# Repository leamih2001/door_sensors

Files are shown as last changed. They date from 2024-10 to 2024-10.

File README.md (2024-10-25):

# door_sensors (Documentation for Access Control System)

1. Introduction
   The aim of the implemented system is to monitor entry and exit into a room, in this case the laboratory, using infrared
   light barriers, whereby photos are taken and facial recognition is then carried out. In this case, there are three main
   services that are orchestrated by the process engine. Communication between the services does not take place directly,
   but is coordinated by the CPEE, whereby the CPEE server calls scripts on the PC via http(s), which ensures, among other
   things, loose coupling and reusability.

2. Overview components
   The hardware components are as follows:
   - Infrared light barriers (LEFRIKO E18-D80NK)
   - Development board (ESP32-WROOM-32E)
   - Webcam (Logitech Streamcam)
   The ESP32 monitors the infrared light barriers and sends events to a central WebSocket client. There are three Flask-based
   services, which are:
   - Sensor Data Retrieval
   - Image Capture
   - Face Recognition

3. Hardware setup: Infrared light barrier and ESP32
   The ESP32 monitors four infrared light barriers, each of which detects people entering or leaving the laboratory. Two are
   mounted further up and the other two further down on the door frame to counteract the physical restrictions. The two
   brackets in which the sensors are located were produced using 3D printing, whereby there is a small opening underneath
   next to the two holes for the light barriers in which the ESP can be attached. The Arduino code regulates the behavior of
   the sensors and a small time delay was implemented to avoid overdetection. As soon as a sensor is triggered by a person
   entering or leaving the room, this event is sent to a websocket client via a message (“ENTRY” or “EXIT”).

4. Software architecture
   The process engine generally queries the sensor data service to determine whether an entry or exit has been detected.
   Based on this information, it triggers the services to perform the corresponding actions.
   
   4.1. Sensor data service
        This receives the events from the ESP via a websocket client and provides a REST endpoint /checkSensor to query the
        current sensor data status.
   
   4.2. Image capture service
        Here, the image is captured with the webcam when an entry or exit is detected. In addition, OpenCV is used here to
        achieve better quality for the subsequent face detection. The images are saved in a local directory and the REST
        endpoint /capture is used to trigger the image capture. The camera buffer is also emptied so that images are not
        simply overwritten.
   
   4.3. Face detection service
        For this service, OpenCV and a pre-trained hair cascade model are used to recognize faces. The REST endpoint /face
        detection is used to transmit the image for recognition.

5. Process
   - Access detection: A person enters (or leaves) the laboratory and thus breaks through the light barrier
     -> This event is registered in the ESP32 and sent to the sensor data service via a WebSocket.
   - Image capture: If “ENTRY” or “EXIT” is detected, the image capture service is called to capture an image of the person.
   - Face recognition: The captured image is forwarded to the face recognition service, which checks whether there are faces
     and, if so, where and how many there are on the captured image.
   - Process Engine: Coordinates the interactions between the services by querying events and initiating the next steps
     based on them.

6. Implementation details
   
   6.1. Arduino (ESP32)
        A WLAN connection is established and a new websocket server is started. In addition, the states of the infrared
        light barriers are read out and their logic is implemented. Depending on which light barrier (outer or inner) is
        broken through first, an entry or exit can be distinguished. At the end, the detected events are sent to the web
        socket client.

   6.2. Pyhonservices
        - Sensor data service: Implements communication via websockets with the ESP32. The service contains a websocket
          client that connects to the websocket server on the ESP and is notified via this connection when a light barrier
          is triggered. Threading is also used to process multiple messages in real time and thus reliably update the sensor
          status.
        - Image acquisition service: Uses OpenCV to capture images and store them in the local file system. A few
          optimizations, such as rotation(s) and resolution settings, have been made to ensure clearer images for face
          recognition.
        - Face recognition service: Processes the captured images and performs face recognition. Here, the recognition
          parameters have also been optimized to achieve better accuracy and consistency of face recognition.

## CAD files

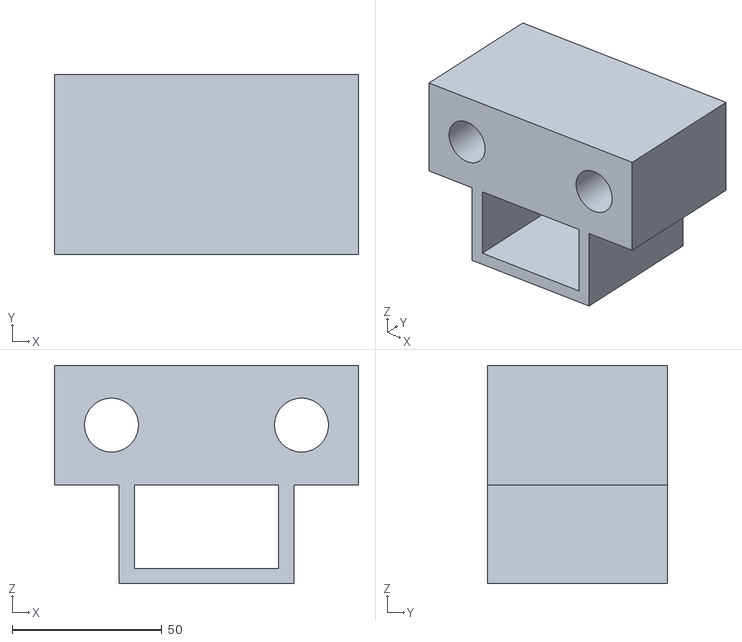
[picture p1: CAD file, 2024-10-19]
3DPrint.stl
101.6 x 60.0 x 73.0

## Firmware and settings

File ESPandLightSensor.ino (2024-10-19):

#include <ArduinoWebsockets.h>
#include <WiFi.h>

// Networkdata
const char* ssid = "Cocktail_Mixer";
const char* password = "process_hubby"; 

// Pins for the lightsensors
// Input for the first light barrier (ENTRY, bottom)
const int SENSOR_1_PIN = 16; 
// Input for the second light barrier (EXIT, bottom)
const int SENSOR_2_PIN = 17; 
// Input for the third light barrier (ENTRY, top)
const int SENSOR_3_PIN = 18; 
// Input for the forth light barrier (EXIT, top)
const int SENSOR_4_PIN = 19; 

// Status variables for the logic implementation of the infrared light barriers
bool entryDetectedBottom = false;
bool exitDetectedBottom = false;
bool entryDetectedTop = false;
bool exitDetectedTop = false;

// Time stamp for deactivation
// Variable for the lower sensors
unsigned long disableTimeBottom = 0;
// Variable for the upper sensors
unsigned long disableTimeTop = 0;  
// 2 second “pause” after breaking through the beam of a light barrier
const unsigned long disableDuration = 2000;

using namespace websockets;

WebsocketsServer server;
WebsocketsClient connectedClient; 

void setup() {
    Serial.begin(115200);
    Serial.println("Connect to WiFi...");

    // Connect to WiFi
    WiFi.begin(ssid, password);
    int retries = 0;
    while (WiFi.status() != WL_CONNECTED && retries < 15) {
        Serial.print(".");
        delay(1000);
        retries++;
    }

    if (WiFi.status() != WL_CONNECTED) {
        Serial.println("\nMistake: No WiFi connection");
        while (true) {
            // The system waits 5 seconds and then repeats the error message
            delay(5000);  
        }
    } else {
        Serial.println("\nWiFi connected");
        Serial.println("IP-Adress: ");
        Serial.println(WiFi.localIP());

        // Starting WebSocket-Server
        server.listen(80);

        // Defining the Pin-Modes
        pinMode(SENSOR_1_PIN, INPUT);
        pinMode(SENSOR_2_PIN, INPUT);
        pinMode(SENSOR_3_PIN, INPUT);
        pinMode(SENSOR_4_PIN, INPUT);
    }
}

void loop() {
    // Accepting the WebSocket connections
    while (!connectedClient.available()) {
        Serial.println("Waiting for Client connections");
        connectedClient = server.accept();

        if (connectedClient.available()) {
            Serial.println("Client connected");
        }
    }

    // Sensor logic only executed when the client is connected
    if (connectedClient.available()) {
        checkSensors();
    } else {
        Serial.println("No Client connected. Sensors deactivated.");
    }
}

void checkSensors() {
    unsigned long currentTime = millis();

    // Querying the individual statuses of the light barriers
    int Sensor1State = digitalRead(SENSOR_1_PIN);
    int Sensor2State = digitalRead(SENSOR_2_PIN);
    int Sensor3State = digitalRead(SENSOR_3_PIN);
    int Sensor4State = digitalRead(SENSOR_4_PIN);

    // Logic for lower sensors (only active if the upper sensors are not deactivated)
    if (currentTime - disableTimeBottom >= disableDuration) {
        if (Sensor1State == LOW && !entryDetectedBottom) { 
            entryDetectedBottom = true;
            Serial.println("Person enters the room (bottom).");
            logAccess("ENTRY (bottom)");
            sendMessageToClient("ENTRY");
            // Upper light barriers deactivated for 2 seconds
            disableTimeTop = currentTime;
            // Lower light barriers deactivated for 2 seconds
            disableTimeBottom = currentTime;
        } 
        else if (Sensor2State == LOW && !exitDetectedBottom) {
            exitDetectedBottom = true;
            Serial.println("Person leaves the room (bottom).");
            logAccess("EXIT (borrom)");
            sendMessageToClient("EXIT");
            // Upper light barriers deactivated for 2 seconds
            disableTimeTop = currentTime; 
            // Lower light barriers deactivated for 2 seconds
            disableTimeBottom = currentTime;
        }
    }

    // Logic for upper sensors (only active if the lower sensors are not deactivated)
    if (currentTime - disableTimeTop >= disableDuration) {
        if (Sensor3State == LOW && !entryDetectedTop) {
            entryDetectedTop = true;
            Serial.println("Person enters the room (top).");
            logAccess("ENTRY (top)");
            sendMessageToClient("ENTRY");
            // Lower light barriers deactivated for 2 seconds
            disableTimeBottom = currentTime; 
            // Upper light barriers deactivated for 2 seconds
            disableTimeTop = currentTime;  
        } 
        else if (Sensor4State == LOW && !exitDetectedTop) {
            exitDetectedTop = true;
            Serial.println("Person leaves the room (top).");
            logAccess("EXIT (top)");
            sendMessageToClient("EXIT");
            // Lower light barriers deactivated for 2 seconds
            disableTimeBottom = currentTime;
            // Upper light barriers deactivated for 2 seconds
            disableTimeTop = currentTime;
        }
    }

    // Reset the status variables when the light barriers are no longer blocked
    if (Sensor1State == HIGH) entryDetectedBottom = false;
    if (Sensor2State == HIGH) exitDetectedBottom = false;
    if (Sensor3State == HIGH) entryDetectedTop = false;
    if (Sensor4State == HIGH) exitDetectedTop = false;
}

// Sends message (if connection is established) to connected WebSocket client
void sendMessageToClient(String message) {
    if (connectedClient.available()) {
        bool success = connectedClient.send(message);
        if (!success) {
            Serial.println("Connection lost. Message could not be sent.");
            // Close due to loss of connection
            connectedClient.close();
        } else {
            Serial.println("Message sent: " + message);
        }
    } else {
        Serial.println("No client connected. Message not sent: " + message);
    }
}

// Logs the transferred access process on the console
void logAccess(String action) {
    Serial.println("Logging access: " + action);
}

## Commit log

2024-10-19 WebSocket
    Flask server for providing HTTP endpoints, WebSocket communication for processing sensor events
2024-10-19 Holder for light barriers and ESP
    [3DPrint.stl]
